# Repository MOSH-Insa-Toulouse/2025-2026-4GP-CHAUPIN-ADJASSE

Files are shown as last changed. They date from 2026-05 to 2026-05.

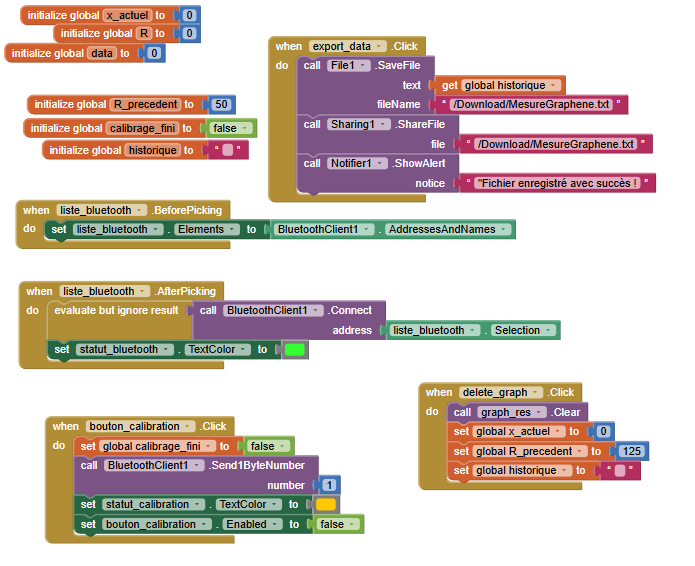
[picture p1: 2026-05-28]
MIT_APP_INVENTOR/blocs1.png

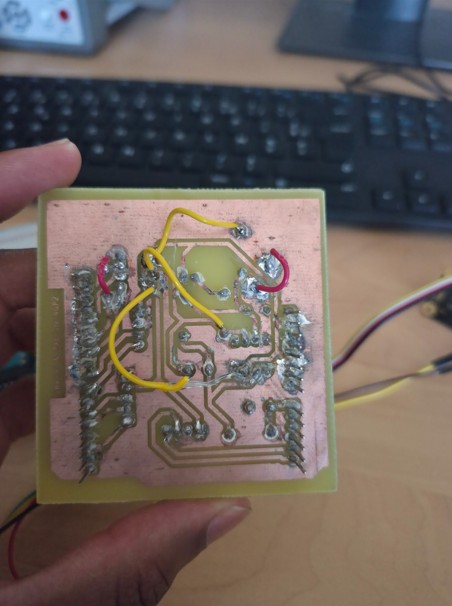
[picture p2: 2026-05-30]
Photos_Captures/soudure_dessous.jpg

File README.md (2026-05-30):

##### **Promotion 2025-2026 Génie Physique INSA TOulouse** — *Marie-Charbel ADJASSE-ABENI & Baptiste CHAUPIN*
**Encadrants :** J. Grisolia, B. Mestre, A. Biganzoli, C. Crouzet

# Projet Capteur

Ce projet collaboratif a pour but de mettre en place une chaîne de mesure complète, autonome et connectée permettant de calibrer, caractériser et analyser en temps réel un capteur de déformation low-tech à base de graphite tracé sur papier. 

Le projet se base directement des travaux de *Lin, CW, Zhao, Z., Kim, J. et al. (2014)* publiés dans *Nature*, intitulés **"Pencil Drawn Strain Gauges and Chemiresistors on Paper"**.

### Contexte & Principe Physique

Le capteur est réalisé par dépôt de graphite sur une feuille de papier (épaisseur $0.35\text{ mm}$) à l'aide de différents crayons (B, 3B, 6B, 2H, HB). Ce dépôt forme un **système granulaire** dont la conductance dépend de la distance inter-grain :
* **En compression** : La distance inter-grain diminue, provoquant une augmentation de la conductance (chute de la résistance).
* **En traction/tension** : La distance augmente, entraînant une hausse de la résistance.

L'objectif de ce projet est de concevoir l'électronique d'acquisition, le système embarqué et l'interface applicative permettant de déduire fidèlement l'angle de flexion et la déformation du papier en fonction de sa résistance.

### Livrables du Projet
1. Un **Shield PCB personnalisé** pour Arduino UNO (mesure, amplification et communication).
2. Un **Code source Arduino (C++)** structuré en machine à états gérant l'acquisition et l'IHM.
3. Une **Application Android (.APK)** sous MIT App Inventor assurant la supervision et le tracé graphique en temps réel.
4. Une **Fiche technique (Datasheet)** de caractérisation du capteur en graphite.

### Composants Utilisés
* **Microcontrôleur :** Carte Arduino UNO Rev 3.
* **Amplification (AOP) :** LTC1050.
* **Passifs d'instrumentation :** Résistances ($2 \times 1\text{ k}\Omega$, $1 \times 10\text{ k}\Omega$, $2 \times 100\text{ k}\Omega$) & Condensateurs ($2 \times 100\text{ nF}$, $1 \times 1\text{ }\mu\text{F}$).
* **Rétroaction Numérique :** Potentiomètre digital SPI MCP41010 ($10\text{ k}\Omega$, $256$ pas).
* **Interface (IHM) :** Écran OLED 0.96" SSD1306 (I2C) & Encodeur rotatif Keyes KY-040.
* **Communication :** Module Bluetooth HC-05.
* **Comparaison avec un capteur disponible sur le marché :** Capteur de flexion commercial (Flex Sensor Flexpoint / LLC 1070) + Résistance de charge de $47\text{ k}\Omega$.

### Fonctionnalités Principales du Système

* **Auto-Calibration Dynamique (Asservissement)** : Compensation automatique de la résistance à plat ($R_0$) du capteur (de l'ordre du $\text{M}\Omega$) via un potentiomètre digital (MCP41010) afin de centrer la tension de repos à $V_{cc}/2$ ($2.5\text{V} \pm 2\%$).
* **Machine à États Finis (FSM)** : Architecture logicielle Arduino robuste structurée en 4 états distincts : `CALIBRATION`, `CHOIX_MENU`, `MESURE` et `AFFICHAGE`.
* **Interface Homme-Machine (IHM) Autonome** : Navigation par encodeur rotatif (gestion par interruptions) à travers des menus dynamiques affichés sur un écran OLED SSD1306 (I2C).
* **Supervision Mobile en Temps Réel** : Application Android dédiée (MIT App Inventor) affichant les graphiques de déformation, les indicateurs de stabilité et un module d'exportation de données scientifiques au format `.txt`.

---

### Simulation Électronique & Conditionnement (LTSpice)

Le capteur de graphite présente une résistance à vide très élevée (de l'ordre du $\text{M}\Omega$ au $\text{G}\Omega$ selon le crayon utilisé). Sous une alimentation de $5\text{V}$, le courant généré est de l'ordre du nanoampère ($\text{nA}$). Un étage d'amplification est indispensable pour adapter le signal à la dynamique du convertisseur analogique-numérique (ADC) de l'Arduino ($0 - 5\text{V}$).

### Circuit Amplificateur Transimpédance (LTC1050)
Pour exploiter le très faible courant traversant le capteur à haute résistance, un montage amplificateur transimpédance a été modélisé sur LTSpice. Le rapport signal/bruit est optimisé par **trois filtres passe-bas** :
1. **Filtre d'entrée (175 Hz)** : Élimine les vibrations mécaniques et tremblements parasites ($C_1 = 100\text{ nF}$, $R_1 = 100\text{ k}\Omega$, // $R_4 = 10\text{ k}\Omega$).
2. **Filtre actif de rétroaction (1.6 Hz)** : Atténue le bruit secteur de $50\text{ Hz}$ du réseau électrique ($C_3 = 1\text{ µF}$, $R_3 = 100\text{ k}\Omega$).
3. **Filtre de sortie (1.6 kHz)** : Élimine les parasites haute fréquence générés par l'électronique ($C_2 = 100\text{nF}$, $R_5 = 1\text{ k}\Omega$).


La fonction de transfert globale liant la tension mesurée par l'ADC ($V_{ADC}$) à la résistance du capteur ($R_c$) est régie par l'équation :

$$V_{ADC} = \left(1 + \frac{R_3}{R_2}\right) \cdot \frac{R_1}{R_1 + R_c + R_5} \cdot V_{cc}$$

D'où l'extraction mathématique de la résistance du capteur opérée par le firmware :

$$R_c = \left(1 + \frac{R_3}{R_2}\right) \cdot R_1 \cdot \frac{V_{cc}}{V_{ADC}} - R_1 - R_5$$

Note : La résistance $R_2$ est ajustée dynamiquement en modifiant l'indice du potentiomètre numérique MCP41010.

---

## Conception & Fabrication du Shield (KiCad)

Le circuit imprimé, conçu sous KiCad et fabriqué par gravure chimique (insolation UV + perchlorure de fer), se branche comme un Shield sur un Arduino Uno.

### Configuration des Broches (Pinout PCB)

| Composant | Rôle / Description | Interface / Broches Arduino |
| :--- | :--- | :--- |
| **AOP LTC1050** | Amplificateur de signal transimpédance | Entrée Analogique `A0` |
| **MCP41010** | Potentiomètre numérique (10 kΩ) | Bus SPI (`CS: D8` ou `D10`, `MOSI: D11`, `SCK: D13`) |
| **OLED 0.96"** | Écran d'affichage I2C (SSD1306) | Bus I2C (`SDA: A4`, `SCL: A5`) |
| **Encodeur** | Navigation dans le menu déroulat de l'écran OLED | Interruptions (`CLK: D2`, `DT: D4`, `SW: D5` ou `D6`) |
| **HC-05 / HC-06** | Module de communication Bluetooth | SoftwareSerial (`RX: D5` ou `D8`, `TX: D3` ou `D7`) |
| **Flex Sensor** | Capteur commercial de comparaison | Pont diviseur de tension ($47\text{ k}\Omega$) |

Un **plan de masse (GND)** étendu a été configuré sur la face cuivre pour stabiliser les potentiels analogiques et atténuer la diaphonie induite par les transmissions RF du Bluetooth.

  

### Modifications Matérielles
Pendant la phase de test du PCB, une correction majeures ont été apportées :
2. **Routage du MCP41010 Révisé** : Le potentiomètre avait d'abord été configuré selon la 1ère démonstration des TD MOSH. 



Cathy a alors réussi à réparer le coup en ajoutant des fils et rayant des pistes de cuivre.



---

### Architecture Logicielle : Machine à États (Arduino)

Le microcontrôleur exécute un algorithme structuré sous forme d'une **Machine à États** pour orchestrer la synchronisation temporelle des tâches.

       [ START ]
           │
           ▼
    ┌──────────────┐
    │ CALIBRATION  │ ───► (Ajuste R2 pour centrer V_A0 à 2.5V)
    └──────┬───────┘
           │ (Équilibre atteint)
           ▼
    ┌──────────────┐
    │  CHOIX_MENU  │ ◄───┐ (Sélection via l'encodeur rotatif)
    └──────┬───────┘     │
           │ (Clic SW)   │ (Clic SW pour quitter)
           ▼             │
    ┌──────────────┐     │
    │ MESURE & AFF │ ────┘ (Transmission Bluetooth 5Hz & OLED)
    └──────────────┘

---

## Interface de Supervision Mobile (MIT App Inventor)

L'application Android sert d'interface de supervision graphique et d'unité d'archivage des mesures.

### Logique Interne des Blocs
1. **Initialisation de la communication ave arduino** : Gestion par voyant et liste pour la connection au module bluetooth.
2. **Gestion de l'Horloge** : La routine cyclique est calée sur un paramètre `TimerInterval` fixe de $200\text{ ms}$ ($5\text{ Hz}$). Dès que l'instruction `BytesAvailableToReceive > 0` est validée, le flux de texte est capturé.
3. **Tracé Dynamique Automatisé** : Le moteur graphique applique un algorithme de défilement horizontal continu sur un composant `Canvas` en stockant la coordonnée $X_{courant}$ et en reliant la coordonnée $Y_{precedent}$ à la valeur rafraîchie, assurant un rendu en temps réel de la déformation.
4. **Enregistrement et Exportation** : Un bloc concatène en continu l'ensemble des mesures dans une variable de type chaîne (`global historique`) intercalée par des sauts de ligne (`\n`) et des points-virgules (`;`). L'appui sur le bouton d'exportation appelle le gestionnaire `File1.SaveFile` pour inscrire le document sous la forme `/MesureGraphene.txt` directement dans l'arborescence physique du téléphone. Cette dernière option n'est malheureuseent pas fonctionnelle (difficulté à trouver l'arborescence exacte sur les téléphones portables).

---

## Banc de Test & Métrologie Expérimentale

Pour calibrer le capteur en graphite, l'équipe a développé un banc de test étagé conçu sur mesure par impression 3D (rayons de courbure étalonnés de $1\text{ cm}$ à $2.5\text{ cm}$ avec des pas de $0.25\text{ cm}$).

### Configuration Mécanique : Traction vs Compression
La fixation mécanique sur les cylindres de calibration s'effectue via des pinces de test Mueller connectées aux zones de contact du film de graphite :
* **Mode Extension / Traction (Tension)** : Le film en U de graphite est orienté vers l'extérieur (face à l'opérateur). La flexion étire mécaniquement le maillage, augmentant la distance inter-grain de la couche de carbone, ce qui induit une élévation de la résistance globale ($R_{capt} \uparrow$).


  
* **Mode Compression** : Le capteur est retourné face blanche apparente, la couche active de graphite étant plaquée directement contre la structure cylindrique du gabarit vert. La courbure comprime les feuillets de graphite, réduisant la barrière tunnel inter-particulaire et provoquant une baisse de la résistance électrique ($R_{capt} \downarrow$).



### Synthèse des Résultats Métrologiques (Datasheet)
Les essais ont permis de comparer les facteurs de jauge (sensibilité $K$) et la répétabilité en fonction de la texture du crayon employé (2H, HB, 2B, 4B, 6B) :
* **Mines Tendres (Crayon 6B)** : Très haute teneur en carbone pur, offrant une excellente conductivité initiale et une très bonne linéarité de la variation relative de résistance en compression. Cependant, la cohésion mécanique est faible, entraînant une perte de matière rapide par friction.
* **Mines Dures (Crayons B et 3B)** : Proportion plus importante de liant argileux. La résistance de base est plus élevée, ce qui génère une sensibilité transimpédance plus nerveuse (facteur de jauge supérieur), mais le signal est sujet à une dérive exponentielle et à des irrégularités, illustrant parfaitement la théorie des milieux granulaires désordonnés.

---

## Conclusion Générale & Perspectives

Ce projet a permis de valider avec succès le développement et l'instrumentation d'une chaîne de mesure **Low-Tech complète et connectée**, de la modélisation analogique à l'application mobile de traitement.

### Évaluation du Potentiel d'Industrialisation
**Avantages** : Coût matière nul, éco-conception évidente, accessibilité universelle, excellente réponse en traction/compression, faible consommation électrique et capteur remplaçable ou réparable instantanément sur le terrain en ré-appliquant du graphite.
**Limitations** : Faible répétabilité due à l'usure mécanique du film (perte de graphite au fil des flexions), instabilité des points de contact des pinces et hystérésis structurelle du support en papier face aux jauges industrielles en polymère kapton.

### Améliorations pour une Viabilité Industrielle
Pour transformer ce démonstrateur en un produit industriellement viable (ex : capteurs jetables à bas coût pour l'analyse ponctuelle de structures ou dispositifs éducatifs), les axes de recherche suivants sont préconisés :
1. **Électrodes de Contact Fixes** : Remplacer la connexion mécanique directe par l'impression de plots permanents pour figer le contact.
2. **Protection des matériaux** : Appliquer une fine couche de plastification ou un vernis protecteur isolant sur le film de graphite afin de figer les grains de carbone. Appliquer un vernis sur le PCB afin d'éviter l'oxydation des pistes de cuivre.

---

## 👥 9. Contacts & Collaborations

Pour toute demande d'information complémentaire ou consultation des fichiers de fabrication vous pouvez contacter l'équipe projet de l'**INSA Toulouse** :

### Équipe Étudiants
* **Marie-Charbel ADJASSE-ABENI** : `adjasse-aben@insa-toulouse.fr`
* **Baptiste CHAUPIN** : `chaupin@insa-toulouse.fr`

### Équipe Enseignants
* **Jérémie Grisolia** (Enseignant-Chercheur, LAAS-CNRS / INSA) : `jeremie.grisolia@insa-toulouse.fr`
* **Benjamin Mestre** (Ingénieur d'Études Électroniques, Scalian) : `benjamin.mestre@scalian.com`
* **Arnauld Biganzoli** (Responsable Instrumentation, INSA) : `arnauld.biganzoli@insa-toulouse.fr`
* **Cathy Crouzet** (Technicienne d'Atelier de Fabrication PCB, INSA) : `crouzet@insa-toulouse.fr`

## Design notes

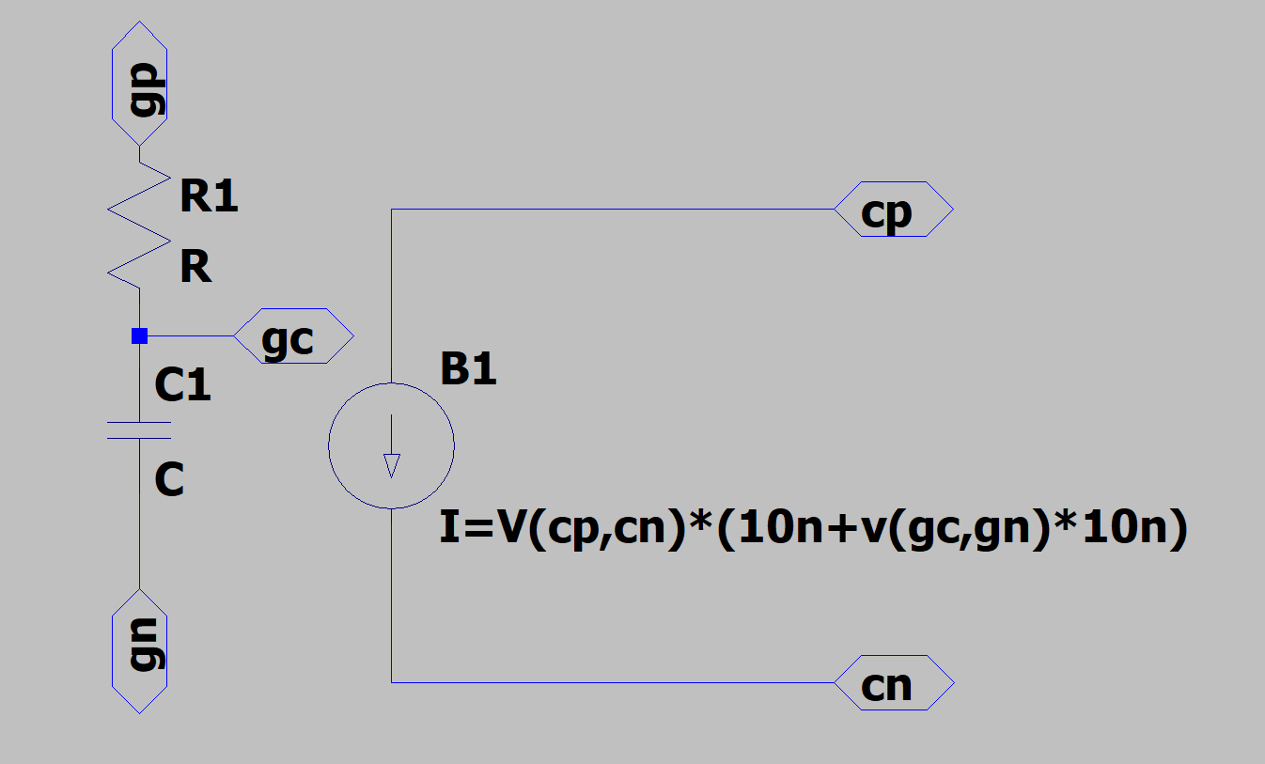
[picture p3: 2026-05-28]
LTSPICE/symb_capt.png

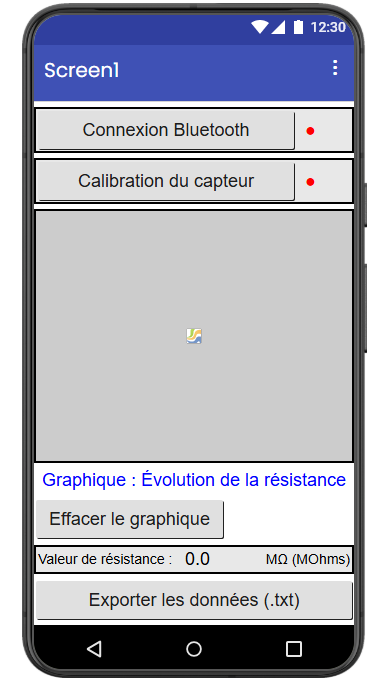
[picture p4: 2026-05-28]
MIT_APP_INVENTOR/face_avant.png

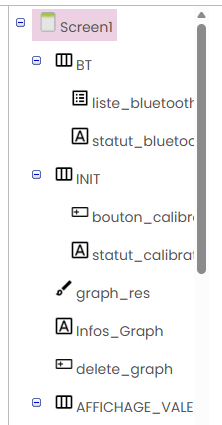
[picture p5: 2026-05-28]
MIT_APP_INVENTOR/config_face_avant1.png

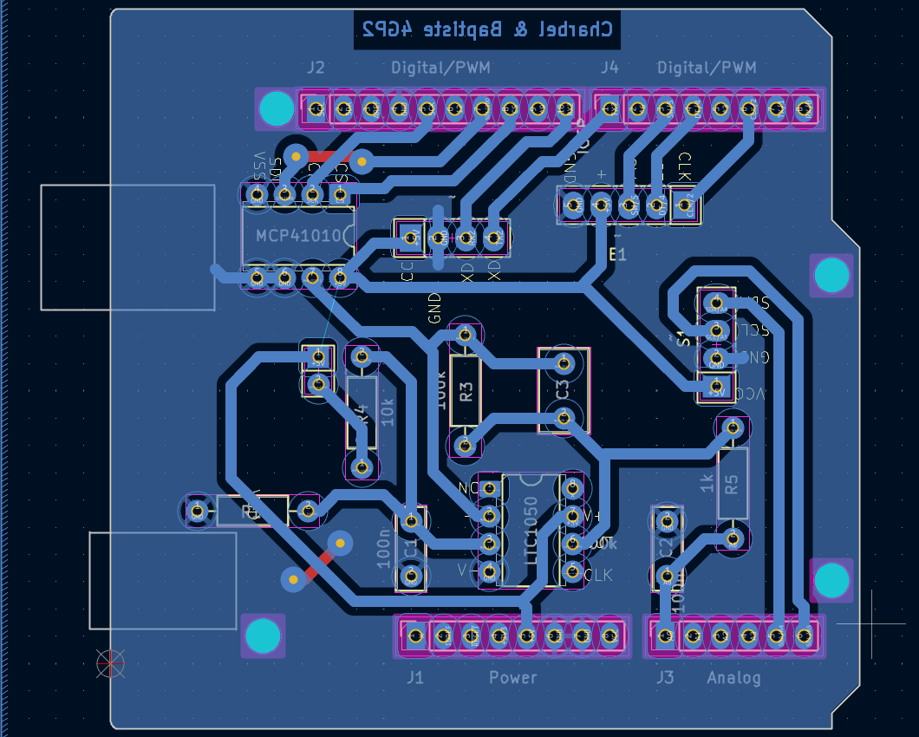
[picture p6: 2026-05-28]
Photos_Captures/capture_pcb.png

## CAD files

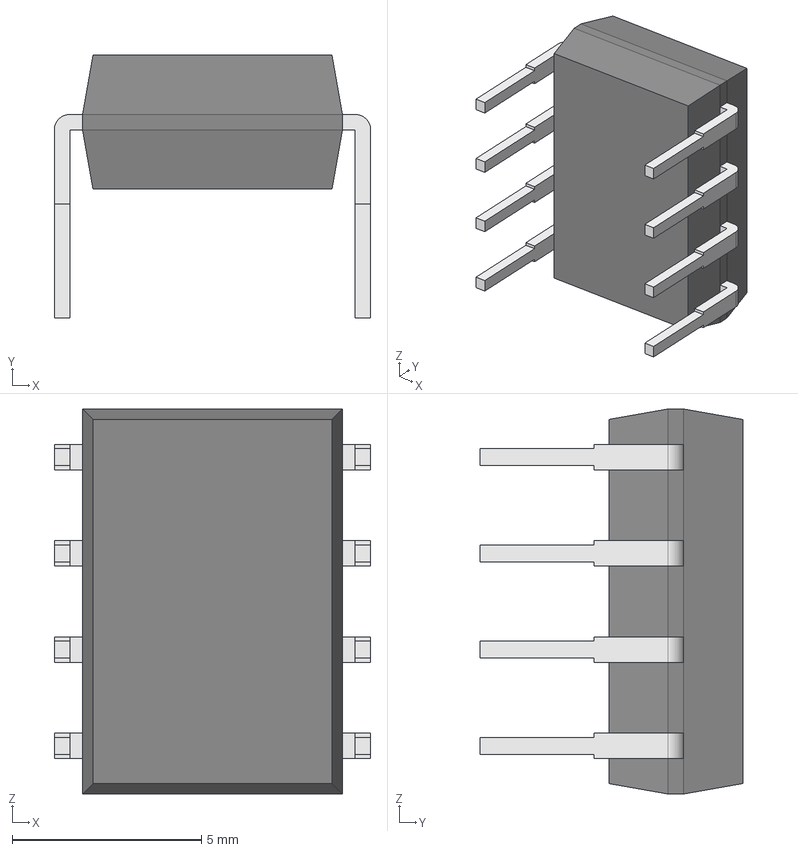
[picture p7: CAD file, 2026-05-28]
Kicad/3D/LTC1050CN8.step
8.35 x 6.93 x 10.2 mm
Body001 (Mirror #1) x 5

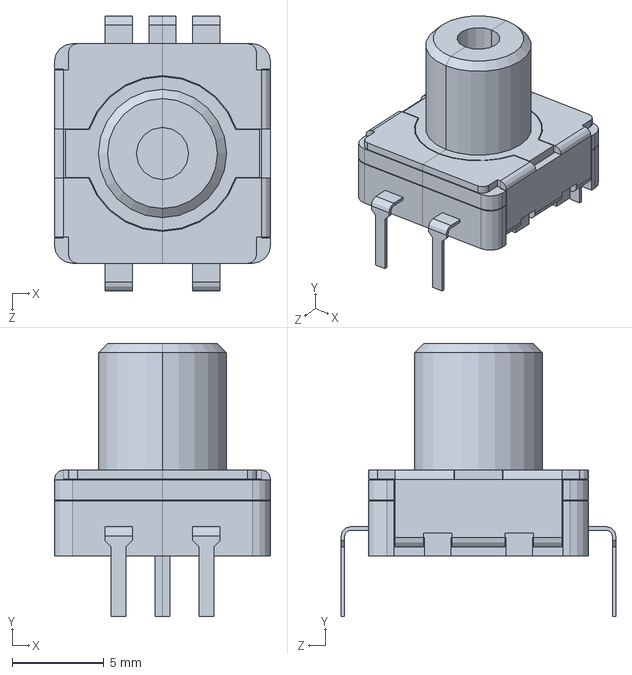
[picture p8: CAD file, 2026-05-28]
Kicad/3D/Rotary Encoder.SLDPRT
11.8 x 14.9 x 15.0 mm

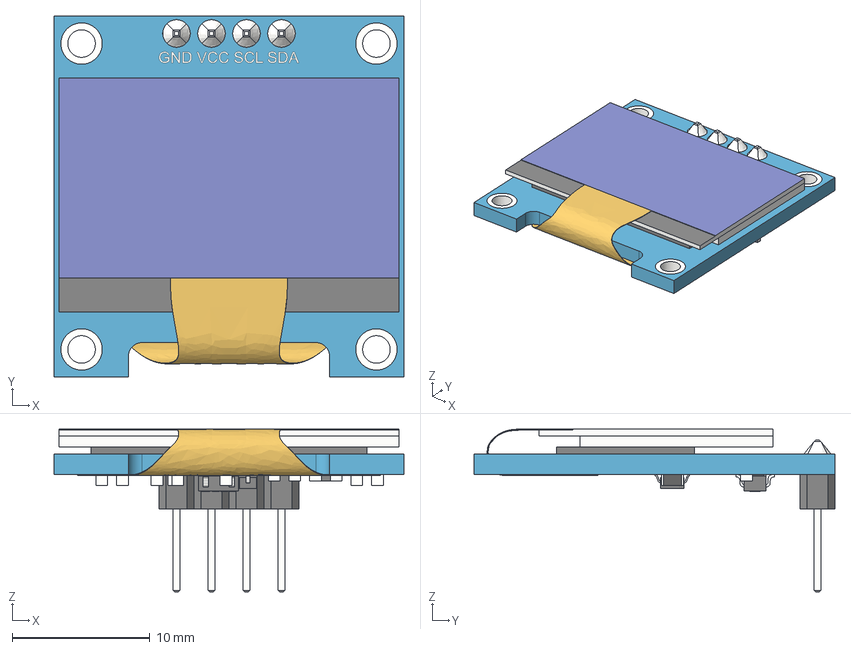
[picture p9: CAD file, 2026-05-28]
Kicad/3D/SSD1306_OLED_Display(128x64).step
25.4 x 26.2 x 11.8 mm
board
screen
pin_header
soldering
smd_capacitor
smd_capacitor (1)
914_smd_resistor
472_smd_resistor x 3
t4_smd_diode
smd_capacitor (2)
smd_capacitor (3)
smd_capacitor (4)
smd_capacitor (5)
smd_capacitor (6)
472_smd_resistor (1)
SOT-23_XC6206 v3
smd_capacitor (7)
flat_cable

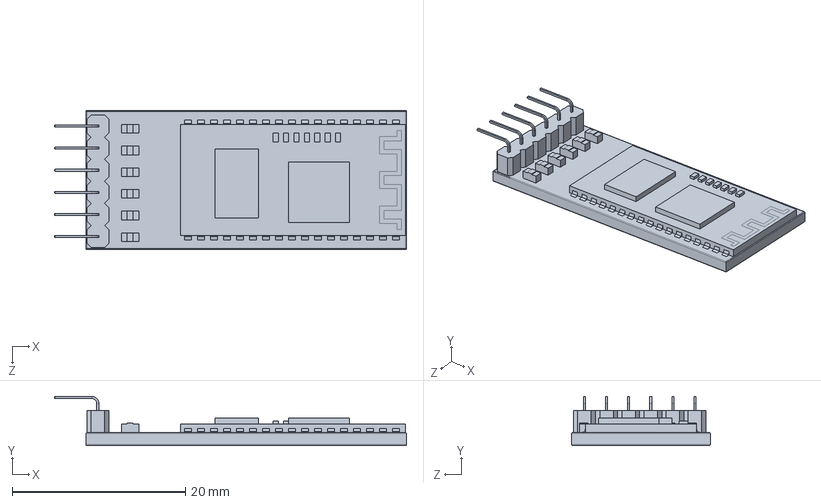
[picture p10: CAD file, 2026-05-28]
Kicad/3D/HC05.STEP
40.6 x 5.67 x 16.0 mm

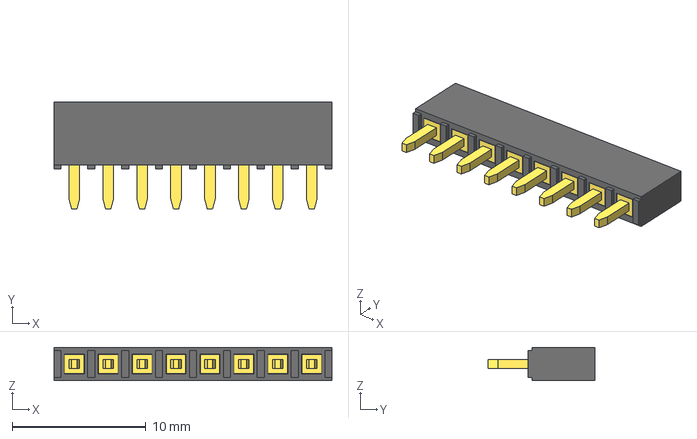
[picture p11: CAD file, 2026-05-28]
Kicad/3D/8-Pin Header - Female - 2.54mm.step
20.8 x 8.00 x 2.50 mm

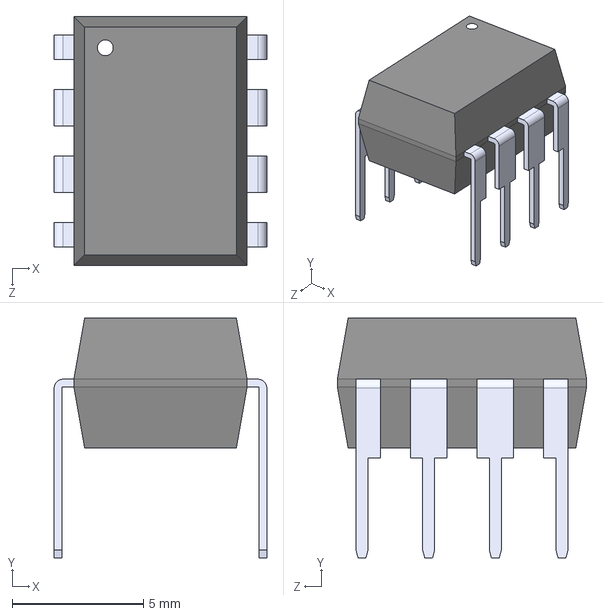
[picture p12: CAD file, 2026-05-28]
Kicad/3D/MCP41010-E_P.step
8.10 x 9.14 x 9.50 mm

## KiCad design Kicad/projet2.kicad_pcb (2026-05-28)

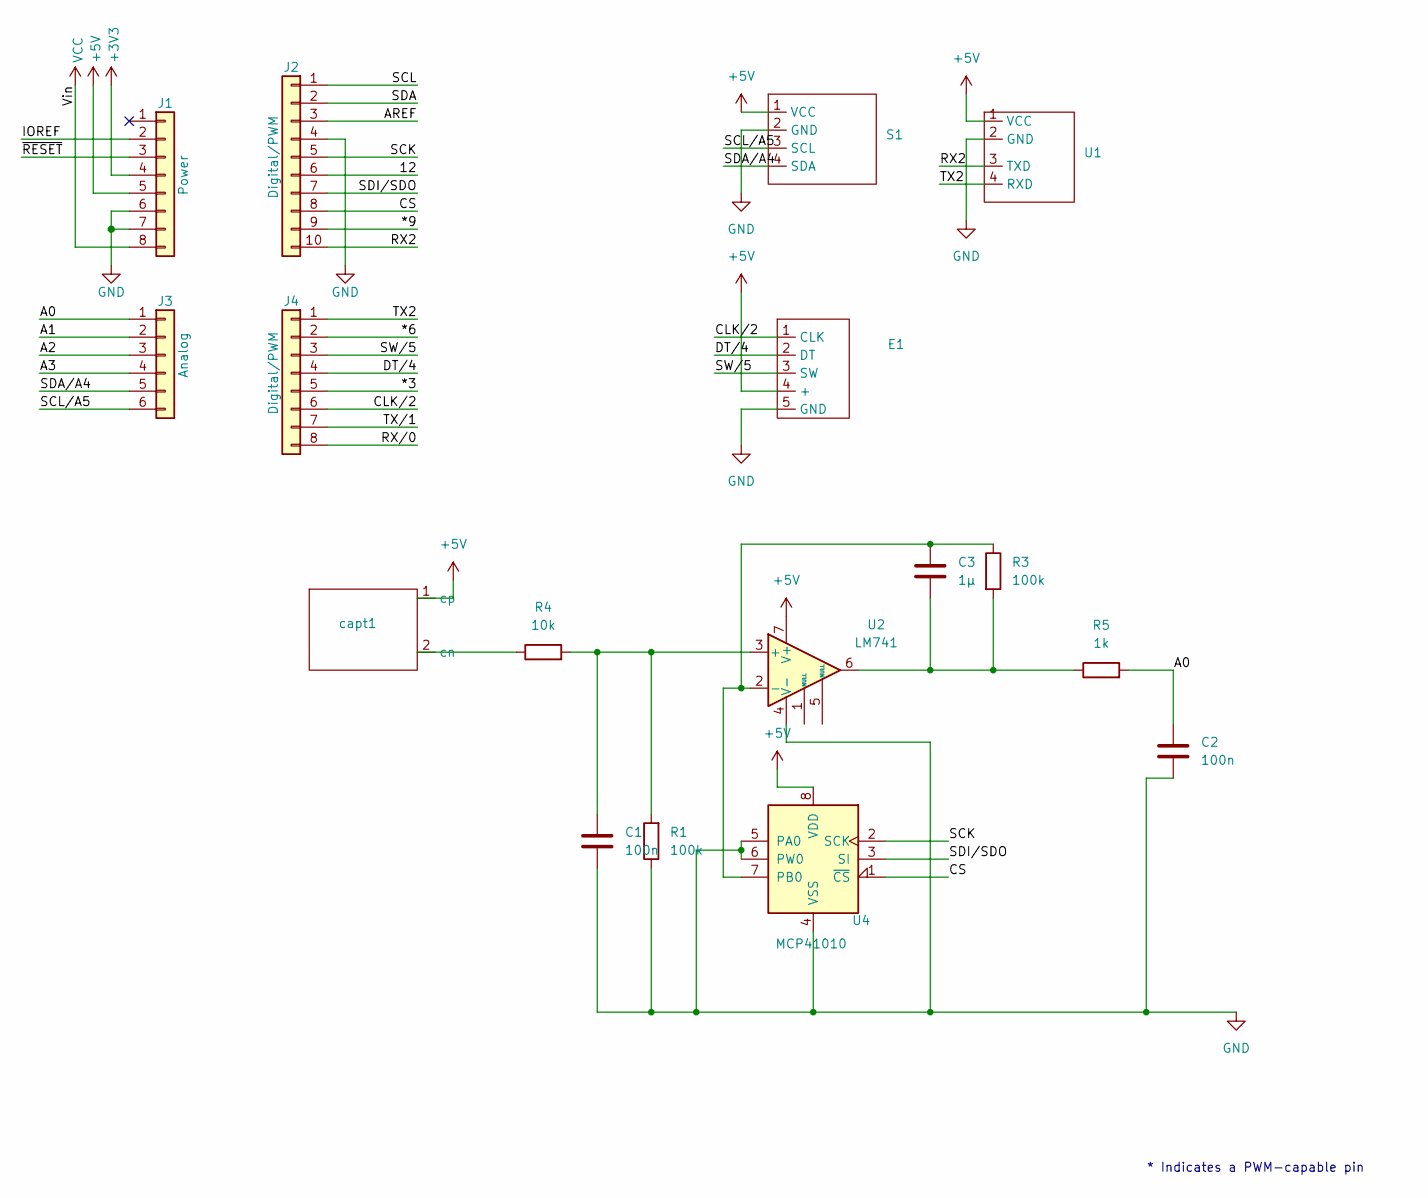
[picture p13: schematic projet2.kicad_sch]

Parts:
C1: 100n; C1
C2: 100n; C2
C3: 1µ; C3
E1: Encodeur
J1: Power; PinSocket_1x08_P2.54mm_Vertical
J2: Digital/PWM; PinSocket_1x10_P2.54mm_Vertical
J3: Analog; PinSocket_1x06_P2.54mm_Vertical
J4: Digital/PWM; PinSocket_1x08_P2.54mm_Vertical
R1: 100k; R1
R3: 100k; R3
R4: 10k; R4
R5: 1k; R5
S1: OLed
U1: Bluetooth
U2: LM741; LTC1050
U4: MCP41010
capt1: CAPTEUR

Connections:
+3V3: J1.4
+5V: E1.4 (+), J1.5, S1.1 (VCC), U1.1 (VCC), U2.7 (V+), U4.8 (VDD), capt1.1 (cp)
/12: J2.6
/*3: J4.5
/*6: J4.2
/*9: J2.9
/A0: C2.1, J3.1, R5.2
/A1: J3.2
/A2: J3.3
/A3: J3.4
/AREF: J2.3
/CLK/2: E1.1 (CLK), J4.6
/CS: J2.8, U4.1 (~CS)
/DT/4: E1.2 (DT), J4.4
/IOREF: J1.2
/RX2: J2.10, U1.3 (TXD)
/RX/0: J4.8
/SCK: J2.5, U4.2 (SCK)
/SCL: J2.1
/SCL/A5: J3.6, S1.3 (SCL)
/SDA: J2.2
/SDA/A4: J3.5, S1.4 (SDA)
/SDI/SDO: J2.7, U4.3 (SI)
/SW/5: E1.3 (SW), J4.3
/TX2: J4.1, U1.4 (RXD)
/TX/1: J4.7
/~RESET: J1.3
GND: C1.2, C2.2, E1.5 (GND), J1.6, J1.7, J2.4, R1.1, S1.2 (GND), U1.2 (GND), U2.4 (V-), U4.4 (VSS), U4.5 (PA0), U4.6 (PW0)
unnamed: C3.2, R3.2, R5.1, U2.6
unnamed: C1.1, R1.2, R4.2, U2.3 (+)
unnamed: C3.1, R3.1, U2.2 (-), U4.7 (PB0)
unnamed: R4.1, capt1.2 (cn)
VCC: J1.8

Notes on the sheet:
* Indicates a PWM-capable pin

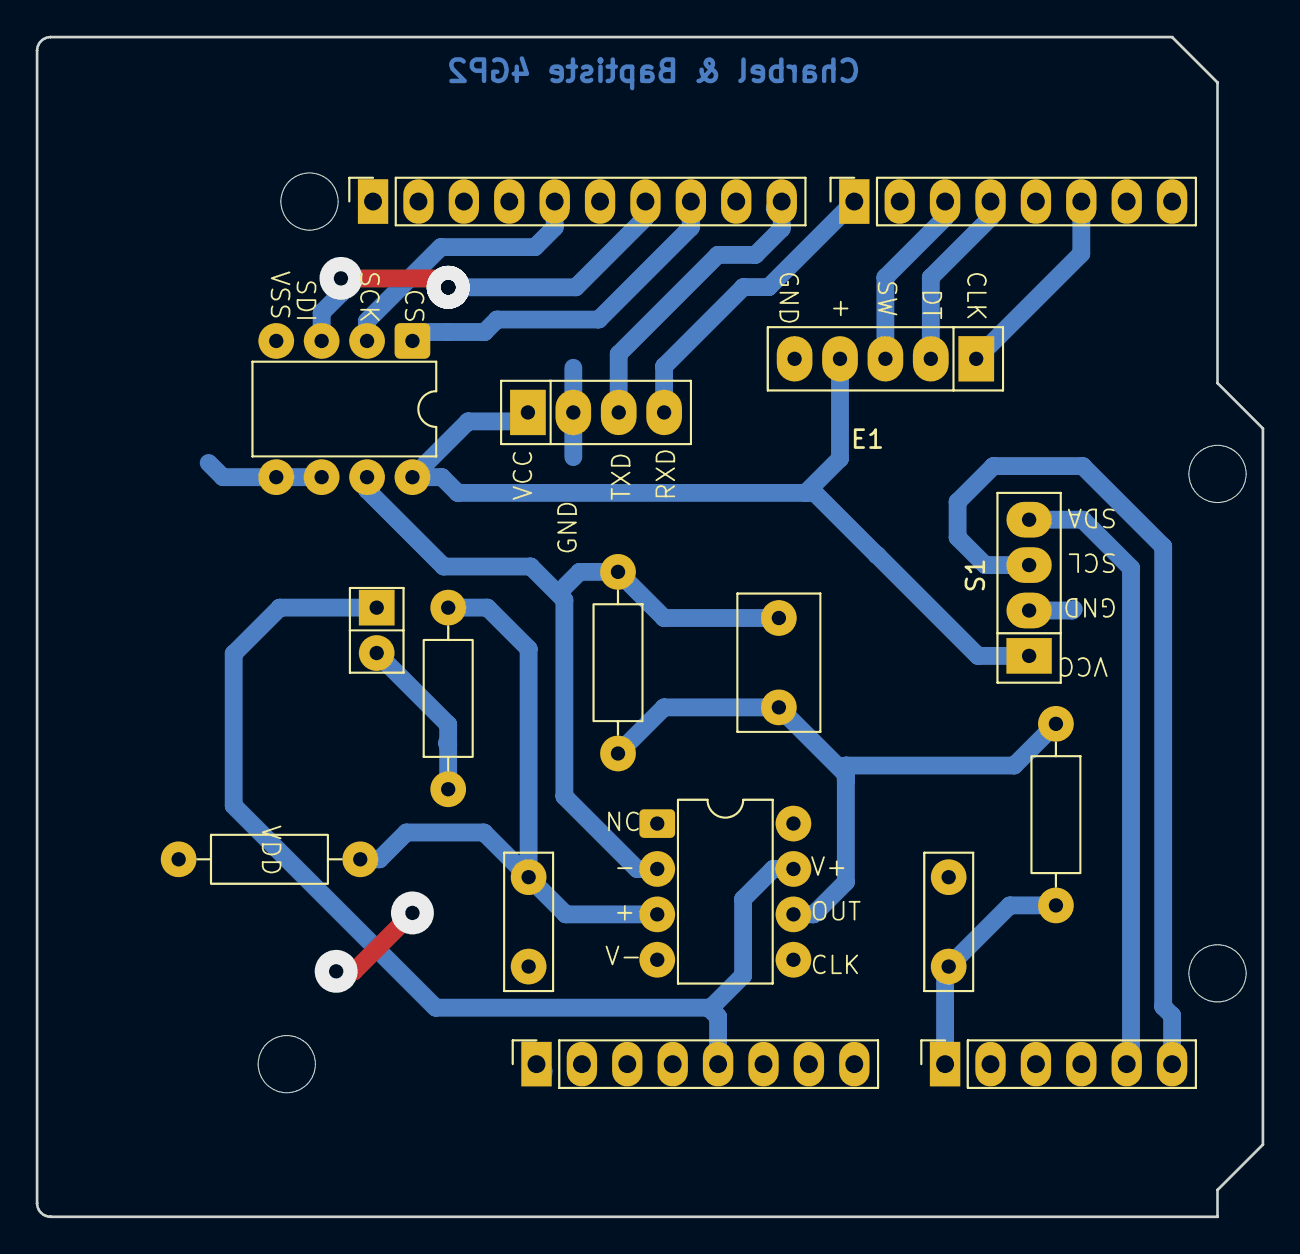
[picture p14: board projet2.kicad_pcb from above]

Board: 2 copper layers, 68.6 x 66.0 mm, 21 parts (0 on the bottom side), 17 nets.

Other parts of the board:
MH1, MH2, MH3, MH4: MountingHole_3.2mm

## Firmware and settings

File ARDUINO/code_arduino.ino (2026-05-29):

/*
 * ============================================================
 *  CAPTEUR GRAPHITE - Machine à états
 * ============================================================
 *  Broches utilisées :
 *    A0        → Capteur graphite
 *    A4 / A5   → SDA / SCL (OLED I2C)
 *    2         → Encodeur CLK
 *    4         → Encodeur DT
 *    3         → Encodeur Switch
 *    7         → BT RX (→ TX du HC-05)
 *    8         → BT TX (→ RX du HC-05)
 *    10        → CS du MCP41010
 *    11/12/13  → MOSI/MISO/SCK SPI
 * ============================================================
 */

/*----------------------- LIBRAIRIES -----------------------*/
#include <Wire.h>
#include <Adafruit_GFX.h>
#include <Adafruit_SSD1306.h>
#include <SPI.h>
#include <SoftwareSerial.h>
#include <String.h>

/*----------------------- OLED -----------------------*/
#define SCREEN_WIDTH  128
#define SCREEN_HEIGHT  64
#define OLED_RESET     -1
#define OLED_ADDR    0x3C
Adafruit_SSD1306 display(SCREEN_WIDTH, SCREEN_HEIGHT, &Wire, OLED_RESET);

/*----------------------- BLUETOOTH -----------------------*/
#define RX_PIN 8   // Broche 7 Arduino → TX du HC-05
#define TX_PIN 7   // Broche 8 Arduino → RX du HC-05
SoftwareSerial Bluetooth(RX_PIN, TX_PIN);

/*----------------------- ENCODEUR -----------------------*/
#define ENC_CLK  2   // Interrupt 0
#define ENC_DT   4
#define ENC_SW   5

/*----------------------- MCP41010 -----------------------*/
#define CS_PIN       10
#define MCP_WRITE  0x11   // Commande écriture pot0
const int   MCP_MAX_POS  = 255;
const float MCP_RAB      = 10000.0;  // Résistance maximale de 10 kΩ

/*----------------------- CONSTANTES DU CIRCUIT -----------------------*/
//  Schéma : amplificateur transimpédance
//    R1 = 100kΩ, R3 = 10kΩ, R4 = 100kΩ, R2 = potentiomètre digital
const float R1  = 100000.0;
const float R3  =  10000.0;
const float R4  = 100000.0;
const float VCC =      5.0;

/*----------------------- VARIABLES GENERALES -----------------------*/
// Machine à états
//  1 = Calibration
//  2 = Menu
//  3 = Mesure (envoi BT + affichage)
int  etat            = 0;   // 0 = attente commande BT initiale
bool calibrage_fini  = false;

// Potentiomètre
int   pos_mcp        = 128; // Position initiale (milieu)
float R2             = 0.0; // Résistance calculée du MCP en Ohm

// Mesures
float V_capteur      = 0.0;
float R_capteur      = 0.0; // en MΩ

// Encodeur
volatile int  encoderValue    = 0;
int           lastEncoderValue = -1;
unsigned long lastButtonTime  = 0;
const int     DEBOUNCE_MS     = 200;

// Menu
const char* menuItems[]  = {"Voir Tension", "Voir Resistance"};
const int   TOTAL_ITEMS  = 2;
int   currentSelection   = 0;
bool  menu_confirme      = false;

// Envoi BT
unsigned long lastSend = 0;
const unsigned long SEND_INTERVAL = 200; // ms

/*=====================================================================
 *  FONCTIONS UTILITAIRES
 *=====================================================================*/

/* --- MCP41010 : écriture SPI --- */
void setPot(int pos) {
  pos = constrain(pos, 0, 255);
  pos_mcp = pos;
  SPI.beginTransaction(SPISettings(14000000, MSBFIRST, SPI_MODE0));
  digitalWrite(CS_PIN, LOW);
  SPI.transfer(MCP_WRITE);
  SPI.transfer((byte)pos);
  digitalWrite(CS_PIN, HIGH);
  SPI.endTransaction();
}

/* --- Calcul résistance R2 du MCP selon position --- */
float calculerR2(int pos) {
  return (MCP_RAB/MCP_MAX_POS)*pos;
}

/* --- Calcul résistance capteur graphite en MΩ --- */
float calculerResistance(float Va0, float r2) {
  if (Va0 <= 0.05) {return 0.0;} // sécurité division par zéro
  float Rcapt = (1.0 + (R4 / r2)) * (R1 * VCC / Va0) - R1 - R3;
  return Rcapt / 1000000.0; // conversion en MΩ
}

/* --- ISR encodeur --- */
void updateEncoder() {
  if (digitalRead(ENC_DT) != digitalRead(ENC_CLK)) {
    encoderValue++;
  } else {
    encoderValue--;
  }
}

/* --- Dessin menu OLED --- */
void drawMenu() {
  display.clearDisplay();
  display.setTextSize(1);
  display.setTextColor(SSD1306_WHITE);
  display.setCursor(0, 0);
  display.println(F("--- MENU ---"));
  display.drawFastHLine(0, 10, 128, SSD1306_WHITE);
  for (int i = 0; i < TOTAL_ITEMS; i++) {
    display.setCursor(0, 18 + i * 12);
    if (i == currentSelection) {
      display.print(F("> "));
    } else {
      display.print(F("  "));
    }
    display.println(menuItems[i]);
  }
  display.setCursor(0, 54);
  display.println(F("Appuyer pour OK"));
  display.display();
}

/*=====================================================================
 *  SETUP
 *=====================================================================*/
void setup() {

  delay(300);

  /* 1. Serial moniteur */
  Serial.begin(9600);
  Serial.println(F("=== Demarrage ==="));

  /* 2. Encodeur */
  pinMode(ENC_CLK, INPUT_PULLUP);
  pinMode(ENC_DT,  INPUT_PULLUP);
  pinMode(ENC_SW,  INPUT_PULLUP);
  attachInterrupt(digitalPinToInterrupt(ENC_CLK), updateEncoder, CHANGE);

  /* 3. OLED — I2C en premier, avant SPI */
  Wire.begin();
  delay(100);
  if (!display.begin(SSD1306_SWITCHCAPVCC, OLED_ADDR)) {
    Serial.println(F("OLED FAIL - boucle infinie"));
    while (1);
  }
  Serial.println(F("OLED OK"));
  display.clearDisplay();
  display.setTextColor(SSD1306_WHITE);
  drawMenu();

  /* 4. SPI + MCP41010 */
  digitalWrite(CS_PIN, HIGH);e
  pinMode(CS_PIN, OUTPUT);
  SPI.begin();
  setPot(pos_mcp); // Position initiale aves le fain de 128
  Serial.println(F("MCP OK"));

  /* 5. Bluetooth en dernier */
  pinMode(RX_PIN, INPUT);
  pinMode(TX_PIN, OUTPUT);
  Bluetooth.begin(9600);
  Serial.println(F("Bluetooth OK"));

  /* 6. Capteur */
  pinMode(A0, INPUT);

  Serial.println(F("=== Setup termine ==="));
}

/*=====================================================================
 *  LOOP
 *=====================================================================*/
void loop() {

  /* --- Lecture capteur (toujours active) --- */
  float lecture = analogRead(A0);
  V_capteur = lecture * (VCC / 1023.0);
  R2        = calculerR2(pos_mcp);
  R_capteur = calculerResistance(V_capteur, R2);

  /* --- Réception commande Bluetooth --- */
  if (Bluetooth.available() > 0) {
    int commande = Bluetooth.read();
    Serial.print(F("BT recu: "));
    Serial.println(commande);

    // L'appli envoie 1 pour démarrer la calibration
    if (commande == 1 && etat == 0) {
      etat = 1;
      calibrage_fini = false;
      Serial.println(F("-> Etat 1 : Calibration"));
    }
  }

  /*=====================================================================
   *  ÉTAT 1 — CALIBRATION
   *  But : asservir pos_mcp pour que V_capteur ≈ 2.5V
   *=====================================================================*/
  if (etat == 1) {

    // Si déjà calibré, on saute directement au menu
    if (calibrage_fini) {
      etat = 2;
    }
    else if (V_capteur > 2.6 && pos_mcp < 256) {
      pos_mcp++;
      setPot(pos_mcp);
      Serial.print("====== Valeur de pos_mpc :");
      Serial.println(pos_mcp);
      Serial.println(V_capteur);

      display.clearDisplay();
      display.setTextSize(1);
      display.setTextColor(SSD1306_WHITE);
      display.setCursor(0,  0); display.print("CALIBRATION");
      display.setCursor(0, 25); display.print(V_capteur); display.print("V -->DOWN");
      display.setCursor(0, 50); display.print("Valeur analogique MCP : "); display.print(pos_mcp);
      display.display();

      delay(80);
    }
    else if (V_capteur < 2.4 && pos_mcp > 1) {
      pos_mcp--;
      setPot(pos_mcp);
      Serial.println(V_capteur);
      Serial.print("====== Valeur de pos_mpc :");
      Serial.println(pos_mcp);

      display.clearDisplay();
      display.setTextSize(1);
      display.setTextColor(SSD1306_WHITE);
      display.setCursor(0,  0); display.print("CALIBRATION");
      display.setCursor(0, 25); display.print(V_capteur);  display.print("V -->UP");
      display.setCursor(0, 50); display.print("Valeur analogique MCP : "); display.print(pos_mcp);
      display.display();

      delay(80);
    }
    else {
      // Tension stabilisée entre 2.4V et 2.6V
      calibrage_fini = true;
      float r2kOhm = calculerR2(pos_mcp) / 1000.0;

      display.clearDisplay();
      display.setTextSize(1);
      display.setTextColor(SSD1306_WHITE);
      display.setCursor(0,  0); display.print("CALIBRATION OK");
      display.setCursor(0, 25); display.print("R2="); + display.print(r2kOhm); display.print(" kOhm");
      display.setCursor(0, 50); display.print("V="); + display.print(V_capteur); display.print(" V");
      display.display();
      Bluetooth.println("OK");
      delay(10000);

      Serial.println(F("Calibration OK"));
      etat = 2;
    }
  }

  /*=====================================================================
   *  ÉTAT 2 — MENU (encodeur rotatif)
   *=====================================================================*/
  else if (etat == 2) {

    menu_confirme = false; // Réinitialise à chaque passage

    // Mise à jour sélection via encodeur
    if (encoderValue != lastEncoderValue) {
      // Navigation circulaire
      if (encoderValue >= TOTAL_ITEMS) encoderValue = 0;
      if (encoderValue < 0)            encoderValue = TOTAL_ITEMS - 1;
      currentSelection = encoderValue;
      lastEncoderValue = encoderValue;
      drawMenu();
    }
    else {
      // Affichage initial du menu
      drawMenu();
    }

    // Appui bouton encodeur = confirmation
    if (digitalRead(ENC_SW) == LOW) {
      if (millis() - lastButtonTime > DEBOUNCE_MS) {
        lastButtonTime = millis();
        menu_confirme  = true;
        Serial.print(F("Menu confirmé : "));
        Serial.println(currentSelection);
        delay(50);
        etat = 3;
      }
    }
  }

  /*=====================================================================
   *  ÉTAT 3 — ENVOI BLUETOOTH
   *=====================================================================*/
  else if (etat == 3) {

    // Envoi toutes les 200ms
    if (millis() - lastSend > SEND_INTERVAL) {
      Serial.println(R_capteur);
      Serial.print(F("MOhms "));
      Bluetooth.println(R_capteur);
      delay(100);
      lastSend = millis();
      etat = 4; // Passe immédiatement à l'affichage
    }

    
  }

  /*=====================================================================
   *  ÉTAT 4 — AFFICHAGE OLED
   *=====================================================================*/
  else if (etat == 4) {

    if (currentSelection == 0) {
      // Affichage tension

      display.clearDisplay();
      display.setTextSize(1);
      display.setTextColor(SSD1306_WHITE);
      display.setCursor(0,  0); display.print("TENSION (A0)");
      display.setCursor(0, 25); display.print(V_capteur, 3); display.print(" V");
      display.setCursor(0, 50); display.print("Clic -> Menu");
      display.display();

    } else {
      // Affichage résistance

      display.clearDisplay();
      display.setTextSize(1);
      display.setTextColor(SSD1306_WHITE);
      display.setCursor(0,  0); display.print("RESISTANCE");
      display.setCursor(0, 25); display.print(R_capteur, 3); display.print("MOhms");   // Affiche la tension avec 3 décimales [cite: 28, 62]
      display.setCursor(0, 50); display.print("Clic -> Menu");
      display.display();
    }

    // Appui bouton = retour menu
    if (digitalRead(ENC_SW) == LOW) {
      if (millis() - lastButtonTime > DEBOUNCE_MS) {
        lastButtonTime = millis();
        Serial.println(F("Retour menu"));
        delay(50);
        etat = 2;
      }
    }
    else {
    etat = 3; // Boucle entre 3 et 4 en permanence
    }
  }

  delay(30); // Légère pause pour stabilité
}

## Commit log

2026-02-10 création du projet
    [flex-sensor.kicad_pcb, flex-sensor.kicad_sch]
2026-02-10 création nouveau projet
    [flex-sensor.kicad_pcb, flex-sensor.kicad_sch, flex_sensor.kicad_pcb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]
2026-05-24 Update README.md
    Il manque les captures d'écran et quelques explications
